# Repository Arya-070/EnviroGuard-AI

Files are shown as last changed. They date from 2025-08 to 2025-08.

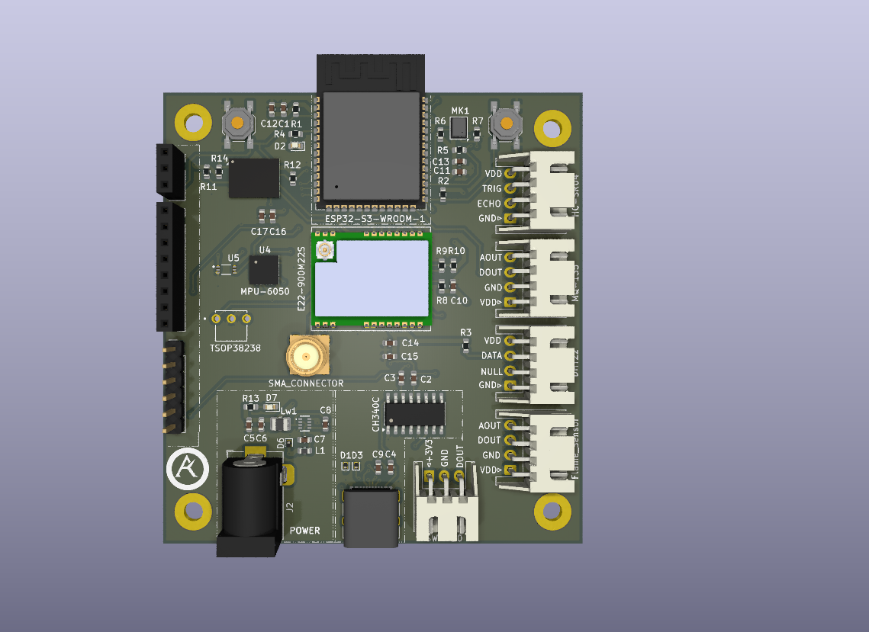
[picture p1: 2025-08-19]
IMAGES/3D_VIEW1.png

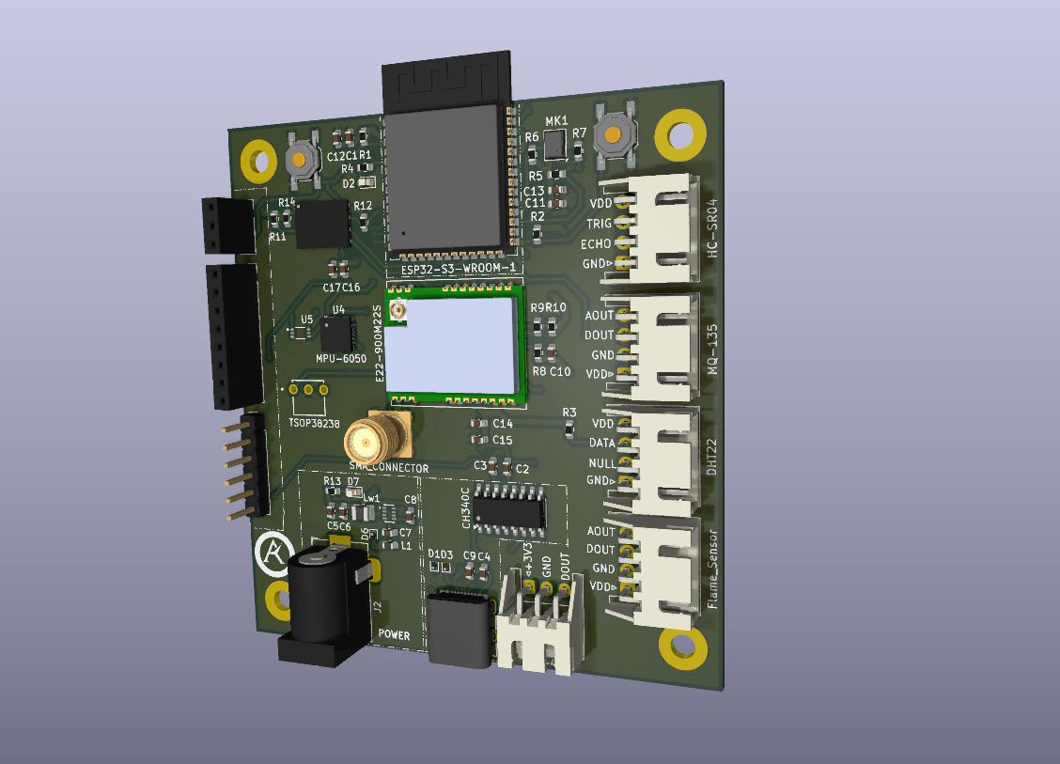
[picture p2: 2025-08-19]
IMAGES/3D_VIEW_2.png

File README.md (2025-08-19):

# 🚀 EnviroGuard-AI
### *A Smart, Modular Infrastructure Monitoring System Powered by Edge AI and ESP32-S3*

---

## 🌍 Overview
**EnviroGuard-AI** is a compact, modular, and powerful anomaly detection system built around the **ESP32-S3-WROOM-1** microcontroller. Designed specifically for smart infrastructure applications, this system brings together multiple environmental sensors, long-range wireless communication, and Edge AI capabilities.

With its **professionally designed 4-layer PCB**, onboard **LoRa (SX1262)**, **QSPI Flash** for TinyML models, and **I2S audio input**, it's ideal for detecting gas leaks, vibrations, fire hazards, and abnormal sounds in real-time. Its modular design makes it perfect for quick prototyping or field deployment.

---

## 🌟 Project Highlights
- 🛠️ Fully custom 4-layer **PCB designed in KiCad 7.0**
- 🔌 Powered via **USB-C** with onboard **CH340C USB-to-Serial** interface
- 💾 Includes **QSPI Flash** for storing Edge AI/TinyML models
- 🎤 Audio anomaly detection via **I2S MEMS microphone**
- 🌫️ Onboard sensors for gas, temperature, humidity, vibration, flame, and light
- 📡 Long-range communication using **SX1262 LoRa module**
- 🔋 Designed for **low-power, high-reliability** use cases
- 🧩 Modular expansion header for future hardware integrations

---

## 📌 GPIO Pinout & Connections

| GPIO Pin | Connected To | Function / Role |
|---|---|---|
| GPIO0 | SW_BOOT | Boot mode selection |
| GPIO1 | CH340C RXD | UART TX |
| GPIO3 | CH340C TXD | UART RX |
| GPIO10 | LED_STATUS | Status LED |
| GPIO4 | MQ135_DATA | Gas Sensor |
| GPIO5 | BH1750_SCL | Light Sensor (I2C) Clock |
| GPIO6 | EXP_IO1 | Expansion GPIO |
| GPIO12 | MPU6050_SDA | I2C Data (Accelerometer) |
| GPIO17 | MPU6050_SCL | I2C Clock (Accelerometer) |
| GPIO18 | FLAME_DO | Flame Sensor Digital Out |
| GPIO19 | MIC_CLK | I2S Clock |
| GPIO20 | MIC_DATA | I2S Data |
| GPIO21 | DHT22_DATA | Temp & Humidity Sensor |
| GPIO24 | LORA_BUSY | LoRa Busy Pin |
| GPIO25 | LORA_MOSI | SPI MOSI |
| GPIO26 | LORA_MISO | SPI MISO |
| GPIO31 | LORA_NSS | LoRa CS |
| GPIO32 | LORA_SCK | SPI Clock |
| GPIO34 | LORA_IRQ0 | LoRa Interrupt |
| GPIO36 | LORA_RST | LoRa Reset |
| GPIO35 | EXP_IO5 | Expansion GPIO |
| EN | EN Switch | Reset Circuit |

---

## 🧠 System Architecture

```mermaid
flowchart TD

    %% === Style Definitions ===
    classDef core fill:#ffe0f0,stroke:#d63384,stroke-width:1px,color:#000;
    classDef comm fill:#fff3cd,stroke:#ffc107,stroke-width:1px,color:#000;
    classDef sensor fill:#d1e7dd,stroke:#0f5132,stroke-width:1px,color:#000;
    classDef audio fill:#dbe4ff,stroke:#4c6ef5,stroke-width:1px,color:#000;
    classDef memory fill:#f8d7da,stroke:#842029,stroke-width:1px,color:#000;
    classDef power fill:#e2e3e5,stroke:#6c757d,stroke-width:1px,color:#000;
    classDef expansion fill:#e7f5ff,stroke:#228be6,stroke-width:1px,color:#000;

    %% === Main Power and MCU ===
    USB_C[USB-C Port]:::power --> Regulator[MP2333 Regulator]:::power
    Regulator --> ESP32S3[ESP32-S3 WROOM-1]:::core

    %% === Interfaces ===
    CH340C[CH340C USB-UART]:::comm --> ESP32S3

    %% === Peripherals ===
    ESP32S3 --> Flash[QSPI Flash Memory]:::memory
    ESP32S3 --> LoRa[SX1262 LoRa Module]:::comm
    ESP32S3 --> Audio[MEMS I2S Microphone]:::audio
    ESP32S3 --> Sensors[Sensor Hub]:::sensor
    ESP32S3 --> Expansion[Expansion IO Header]:::expansion

    %% === Sensors ===
    Sensors --> MQ135[MQ135 Gas Sensor]:::sensor
    Sensors --> MPU6050[MPU6050 Accelerometer]:::sensor
    Sensors --> Flame[Flame Sensor]:::sensor
    Sensors --> DHT22[DHT22 Temp & Humidity Sensor]:::sensor
    Sensors --> BH1750[BH1750 Light Sensor]:::sensor
```

---

## 🧩 Component Summary

| No. | Component | Interface | Description |
|-----|---|---|---|
| 1 | ESP32-S3-WROOM-1 | - | Main MCU with AI, BLE, WiFi |
| 2 | SX1262 LoRa Module | SPI | Long-range wireless communication |
| 3 | MEMS I2S Microphone | I2S | Captures audio for analysis |
| 4 | MQ135 | Analog | Gas and air quality sensing |
| 5 | MPU6050 | I2C | Vibration/motion detection |
| 6 | DHT22 | Digital | Temperature & Humidity |
| 7 | BH1750 | I2C | Ambient light measurement |
| 8 | Flame Sensor (4-pin) | Digital | Detects flame or fire presence |
| 9 | CH340C | UART | USB-to-Serial for flashing and debug |
| 10  | QSPI Flash (W25Q32JV)  | QSPI | Stores ML models for inference |
| 11  | USB-C Port | Power | Power and programming port |
| 12  | MP2333 Regulator | Power | Converts 5V to 3.3V efficiently |
| 13  | Expansion Header | GPIO | Breakout pins for add-ons and testing |

---

## 📁 Folder Structure
```bash
EnviroGuard-AI/
│
├── README.md               
├── LICENSE                  
├── .gitignore               
│
├── EnviroGuard-AI_KiCAD_File/      
│   ├── EnviroGuard-AI.kicad_sch    
│   ├── EnviroGuard-AI.kicad_pcb    
│   ├── EnviroGuard-AI.pro          
│   ├── SCH_AUDIO_INPUT.kicad_sch    
│   ├── SCH_COMMUNICATION.kicad_sch  
│   ├── SCH_ENV_SENSORS.kicad_sch   
│   ├── SCH_EXPANSION.kicad_sch    
│   ├── SCH_MCU_CORE.kicad_sch      
│   ├── SCH_POWER_MANAGEMENT.kicad_sch 
│   ├── SCH_QSPI_STORAGE.kicad_sch   
│             
│
├── GERBER/                  
│   └── EnviroGuard-AI-Gerber.zip
│
IMAGES/    
│     ├── 3D_VIEW_1.png
│     ├── 3D_VIEW_2.png
│     ├── B.CU.png
│     ├── F.CU.png
│     ├── In1.CU.png
│     ├── In2.CU.png
│     ├── EDITOR_VIEW.png
│     ├── SCH_AUDIO_INPUT.png
│     ├── SCH_COMMUNICATION.png
│     ├── SCH_ENV_SENSORS.png
│     ├── SCH_EXPANSION.png
│     ├── SCH_MCU_CORE.png
│     ├── SCH_POWER_MANAGEMENT.png
│     ├── SCH_QSPI_STORAGE.png
│     ├── SCHEMATIC_ROOT.png
│     ├── SYSTEM_ARCHITECTURE.png
│     └── COMPONENTS_DOWNLOADED              
└── Backup_ZIP/             
    └── EnviroGuard-AI-backups/

```

---

## 🌱 Future Improvements
- Add a buzzer or RGB LED for better visual/audio alerts
- Enable deep sleep mode to save power during idle states
- Integrate a solar charging module (e.g., TP4056 or BQ24210)
- LoRaWAN gateway integration with cloud sync
- Run a trained ML model for local anomaly classification
- Add a companion web dashboard or mobile app

---

## 🌐 License
This project is released under the **MIT License**. You’re free to use, modify, and share it as you like.

---

## 🤝 Contributions & Feedback
- Found an issue? Open a GitHub issue.
- Have ideas or want to contribute? Pull requests are welcome.
- Collaborators in AI, IoT, or hardware design — feel free to connect!

---

**Let’s build a smarter, safer world with modular edge intelligence — one node at a time. ✨**

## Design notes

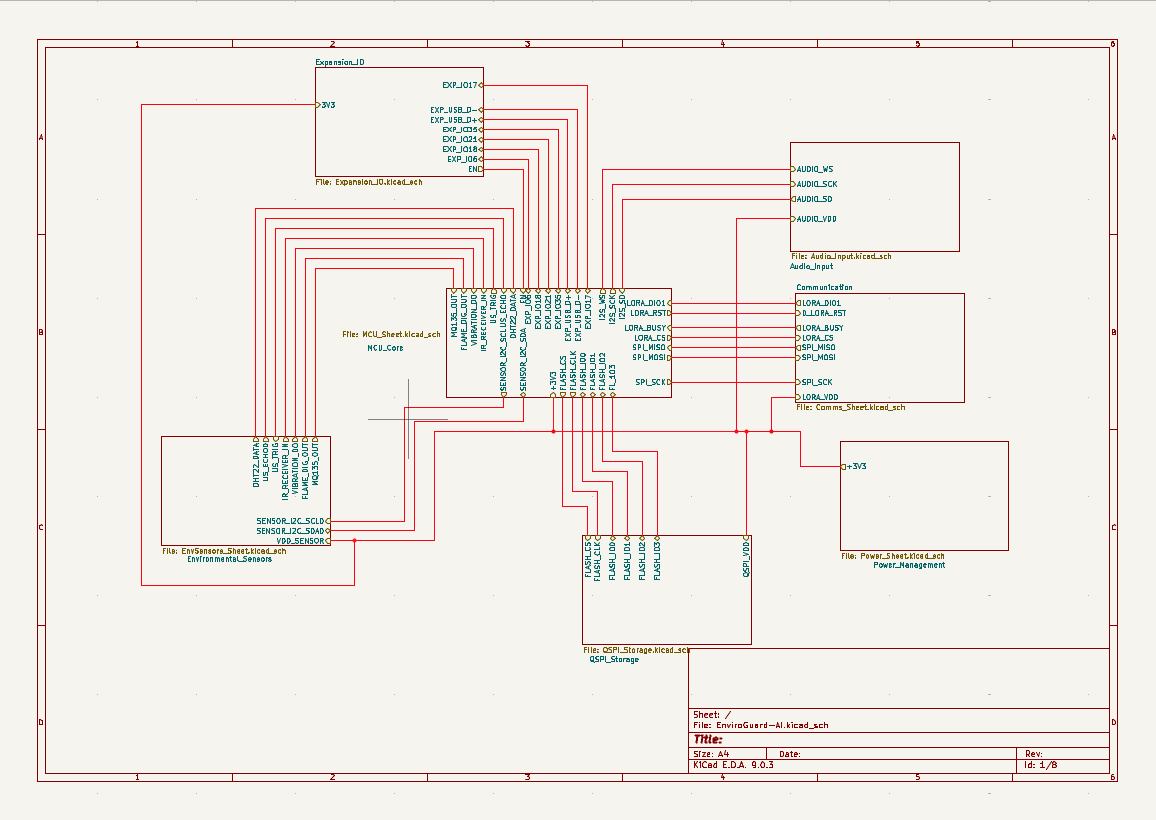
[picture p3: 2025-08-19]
IMAGES/SCHEMATIC_ROOT.png

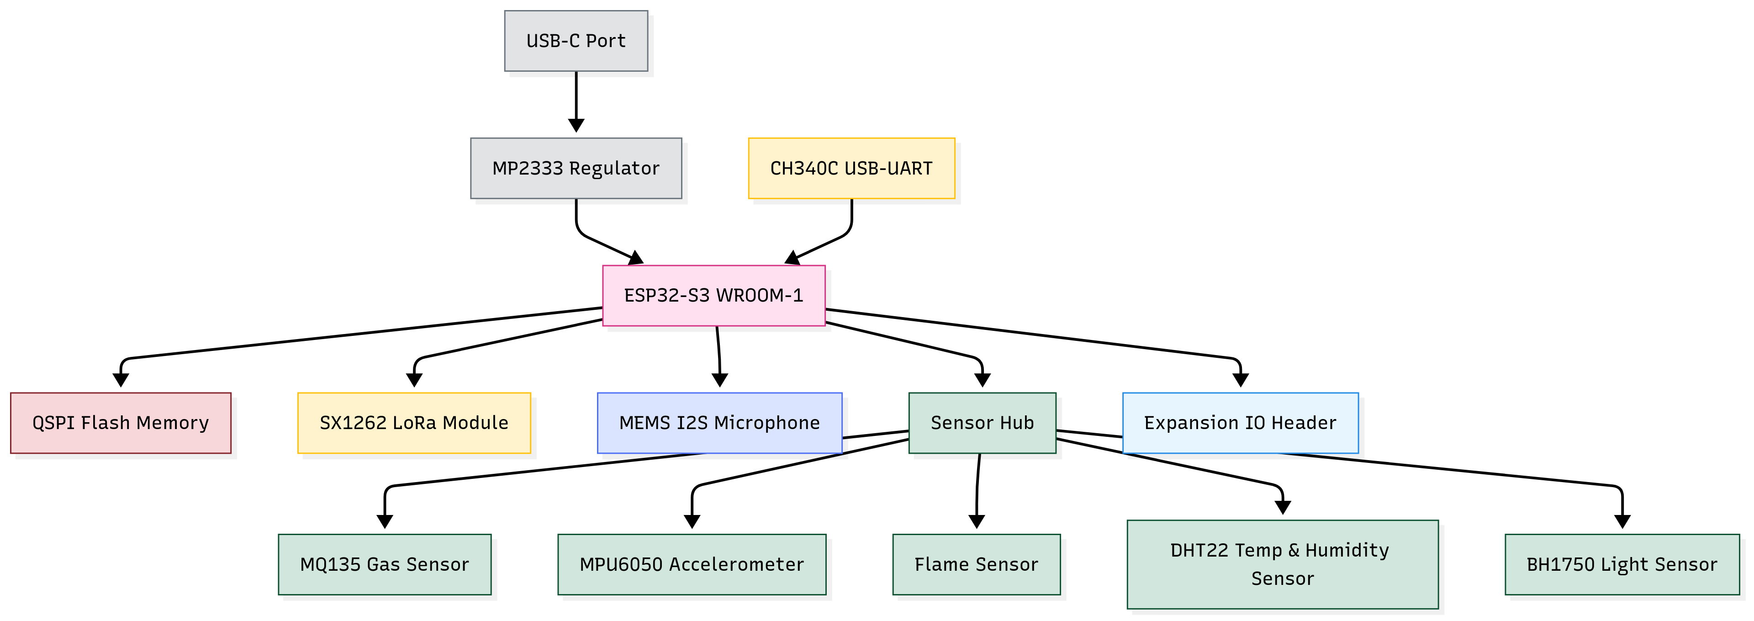
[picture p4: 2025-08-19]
IMAGES/SYSTEM_ARCHITECTURE.png

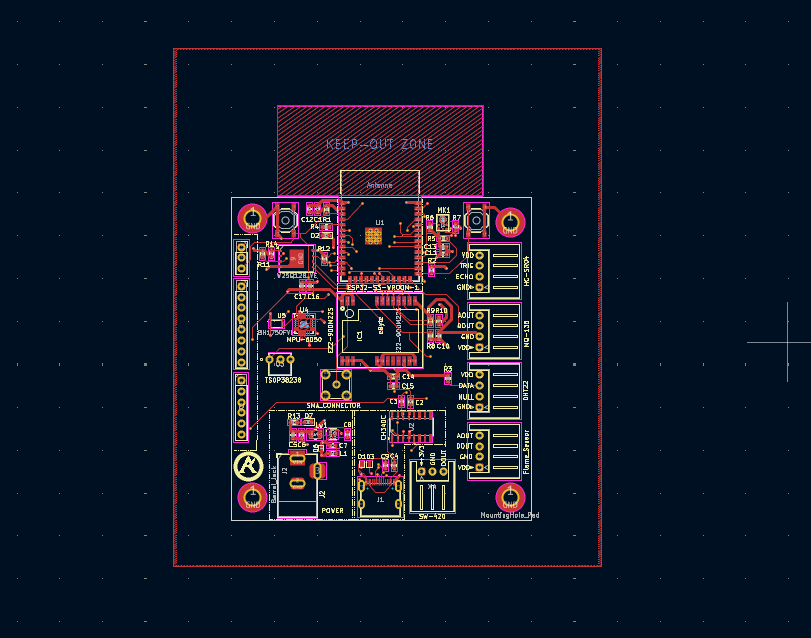
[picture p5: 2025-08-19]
IMAGES/F.CU.png

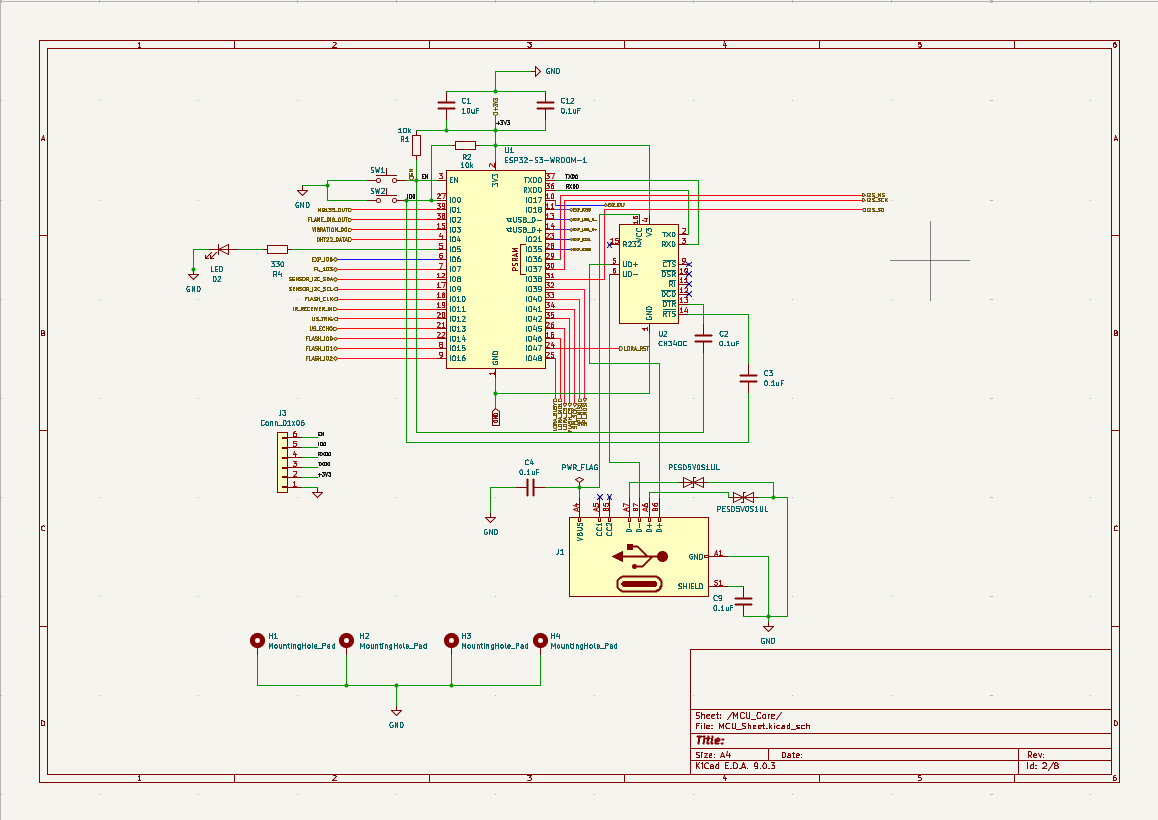
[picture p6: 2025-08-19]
IMAGES/SCH_MCU_CORE.png

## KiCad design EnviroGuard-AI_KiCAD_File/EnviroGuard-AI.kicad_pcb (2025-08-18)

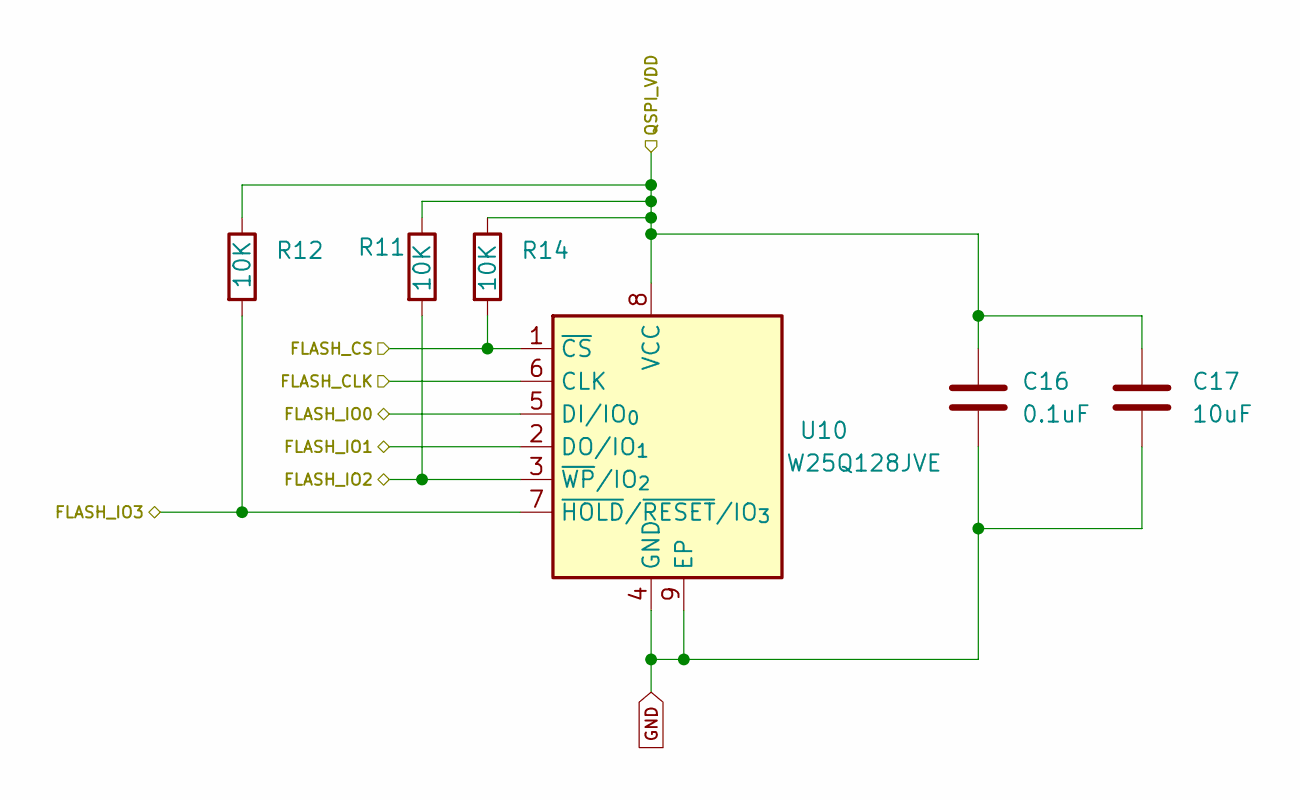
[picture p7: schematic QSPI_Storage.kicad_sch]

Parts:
C16: 0.1uF; C_0603_1608Metric
C17: 10uF; C_0603_1608Metric
R11, R12, R14: 10K; R_0603_1608Metric
U10: W25Q128JVE; WSON-8-1EP_8x6mm_P1.27mm_EP3.4x4.3mm

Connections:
/MCU_Core/+3V3: C16.1, C17.1, R11.1, R12.1, R14.1, U10.8 (VCC); also elsewhere on the board
/MCU_Core/FLASH_CLK: U10.6 (CLK); also elsewhere on the board
/MCU_Core/FLASH_CS: R14.2, U10.1 (~CS); also elsewhere on the board
/MCU_Core/FLASH_IO0: U10.5 (DI/IO_{0}); also elsewhere on the board
/MCU_Core/FLASH_IO1: U10.2 (DO/IO_{1}); also elsewhere on the board
/MCU_Core/FLASH_IO2: R11.2, U10.3 (~WP/IO_{2}); also elsewhere on the board
/MCU_Core/FL_1O3: R12.2, U10.7 (~HOLD/~RESET/IO_{3}); also elsewhere on the board
GND: C16.2, C17.2, U10.4 (GND), U10.9 (EP); also elsewhere on the board

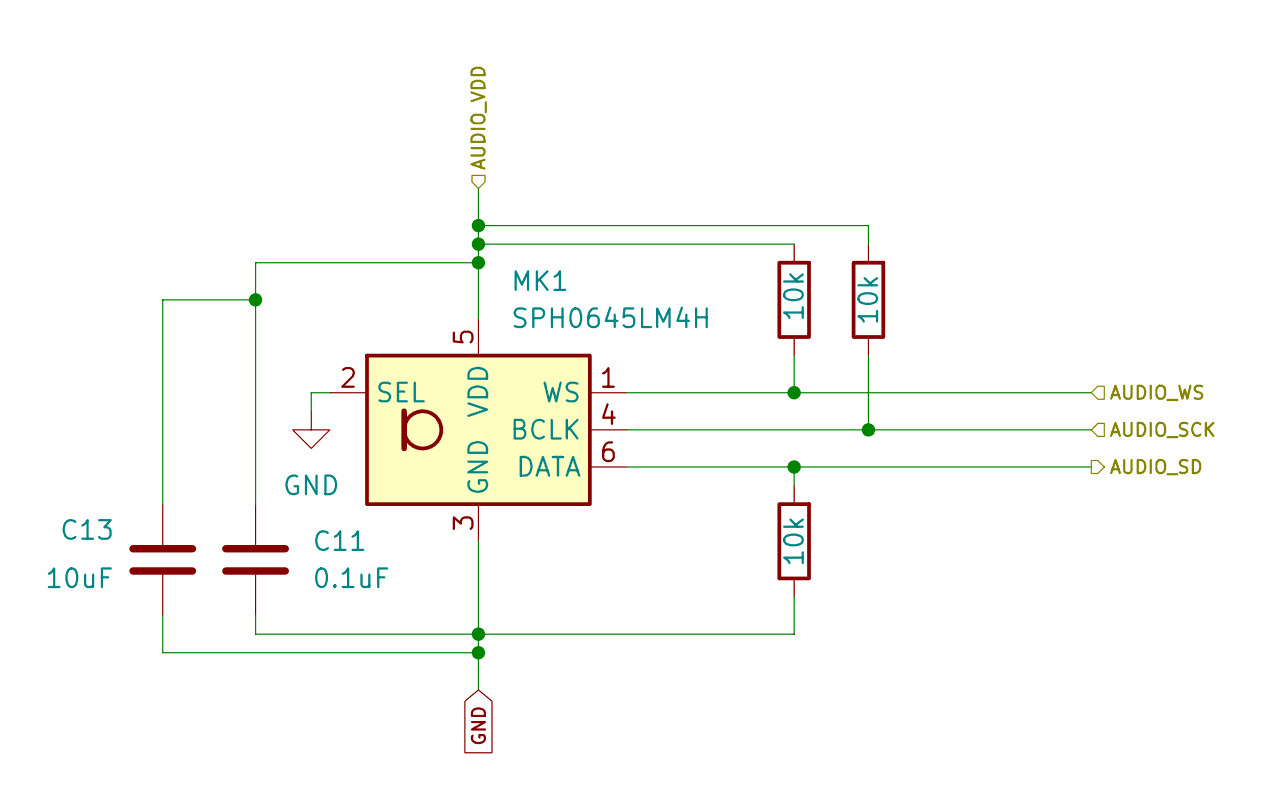
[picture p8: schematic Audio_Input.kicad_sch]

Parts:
C11: 0.1uF; C_0603_1608Metric
C13: 10uF; C_0603_1608Metric
MK1: SPH0645LM4H; Knowles_SPH0645LM4H-6_3.5x2.65mm
R5, R6, R7: 10k; R_0603_1608Metric

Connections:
/Audio_Input/AUDIO_SCK: MK1.4 (BCLK), R6.1; also elsewhere on the board
/Audio_Input/AUDIO_SD: MK1.6 (DATA), R7.2; also elsewhere on the board
/Audio_Input/AUDIO_WS: MK1.1 (WS), R5.1; also elsewhere on the board
/MCU_Core/+3V3: C11.1, C13.1, MK1.5 (VDD), R5.2, R6.2; also elsewhere on the board
GND: C11.2, C13.2, MK1.2 (SEL), MK1.3 (GND), R7.1; also elsewhere on the board

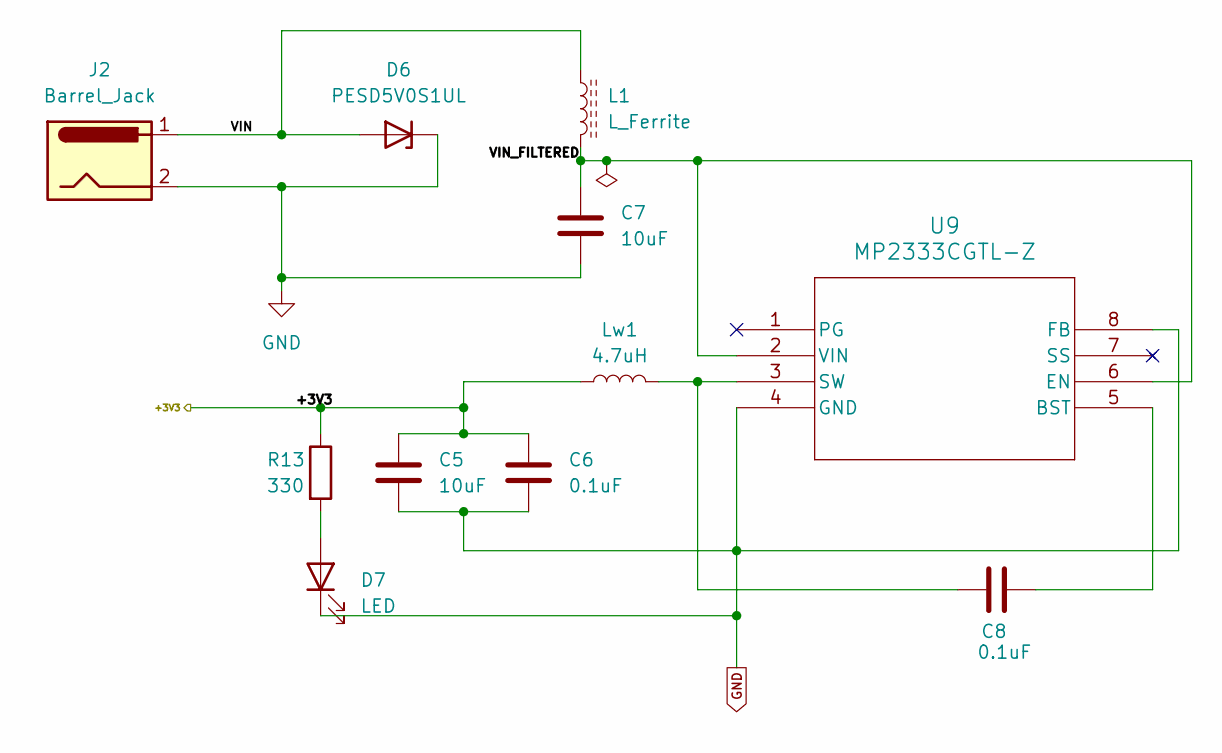
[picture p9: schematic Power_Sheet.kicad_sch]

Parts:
C5, C7: 10uF; C_0603_1608Metric
C6, C8: 0.1uF; C_0603_1608Metric
D6: PESD5V0S1UL; D_SOD-882
D7: LED; LED_0603_1608Metric
J2: Barrel_Jack; BarrelJack_Horizontal
L1: L_Ferrite; L_0603_1608Metric
Lw1: 4.7uH; L_1008_2520Metric
R13: 330; R_0603_1608Metric
U9: MP2333CGTL-Z; SOT583_MP2333C_MNP

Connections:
/MCU_Core/+3V3: C5.1, C6.1, Lw1.1, R13.1; also elsewhere on the board
/Power_Management/VIN: D6.2 (A), J2.1, L1.1
/Power_Management/VIN_FILTERED: C7.1, L1.2, U9.2 (VIN), U9.6 (EN)
GND: C5.2, C6.2, C7.2, D6.1 (K), D7.1 (K), J2.2, U9.4 (GND), U9.8 (FB); also elsewhere on the board
unnamed: D7.2 (A), R13.2
unnamed: C8.1, U9.5 (BST)
unnamed: C8.2, Lw1.2, U9.3 (SW)

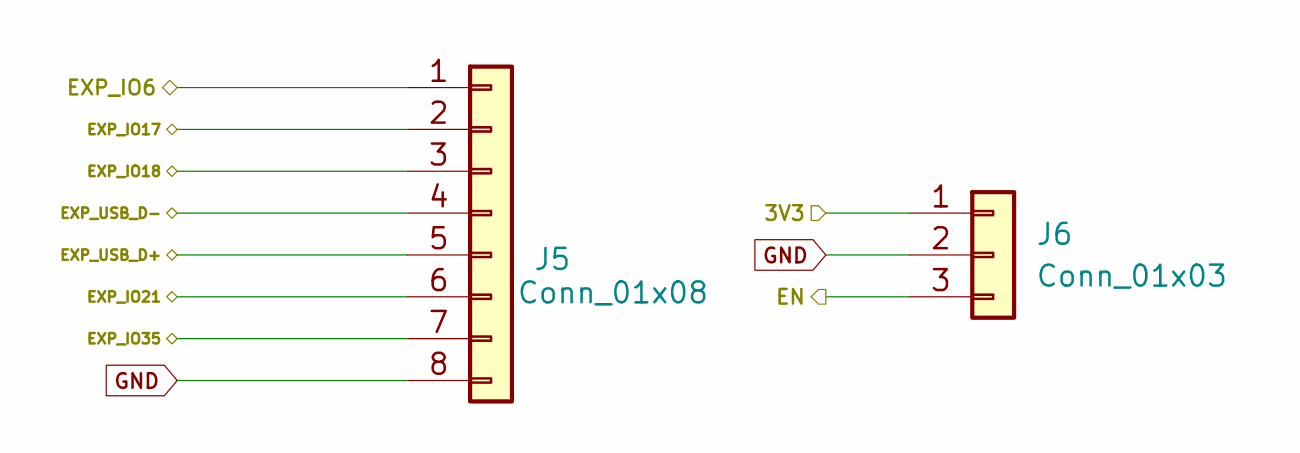
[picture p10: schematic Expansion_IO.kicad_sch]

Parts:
J5: Conn_01x08; PinSocket_1x08_P2.54mm_Vertical
J6: Conn_01x03; PinSocket_1x03_P2.54mm_Vertical

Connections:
/Expansion_IO/EXP_IO6: J5.1; also elsewhere on the board
/Expansion_IO/EXP_IO17: J5.2; also elsewhere on the board
/Expansion_IO/EXP_IO18: J5.3; also elsewhere on the board
/Expansion_IO/EXP_IO21: J5.6; also elsewhere on the board
/Expansion_IO/EXP_IO35: J5.7; also elsewhere on the board
/Expansion_IO/EXP_USB_D+: J5.5; also elsewhere on the board
/Expansion_IO/EXP_USB_D-: J5.4; also elsewhere on the board
/MCU_Core/+3V3: J6.1; also elsewhere on the board
/MCU_Core/EN: J6.3; also elsewhere on the board
GND: J5.8, J6.2; also elsewhere on the board

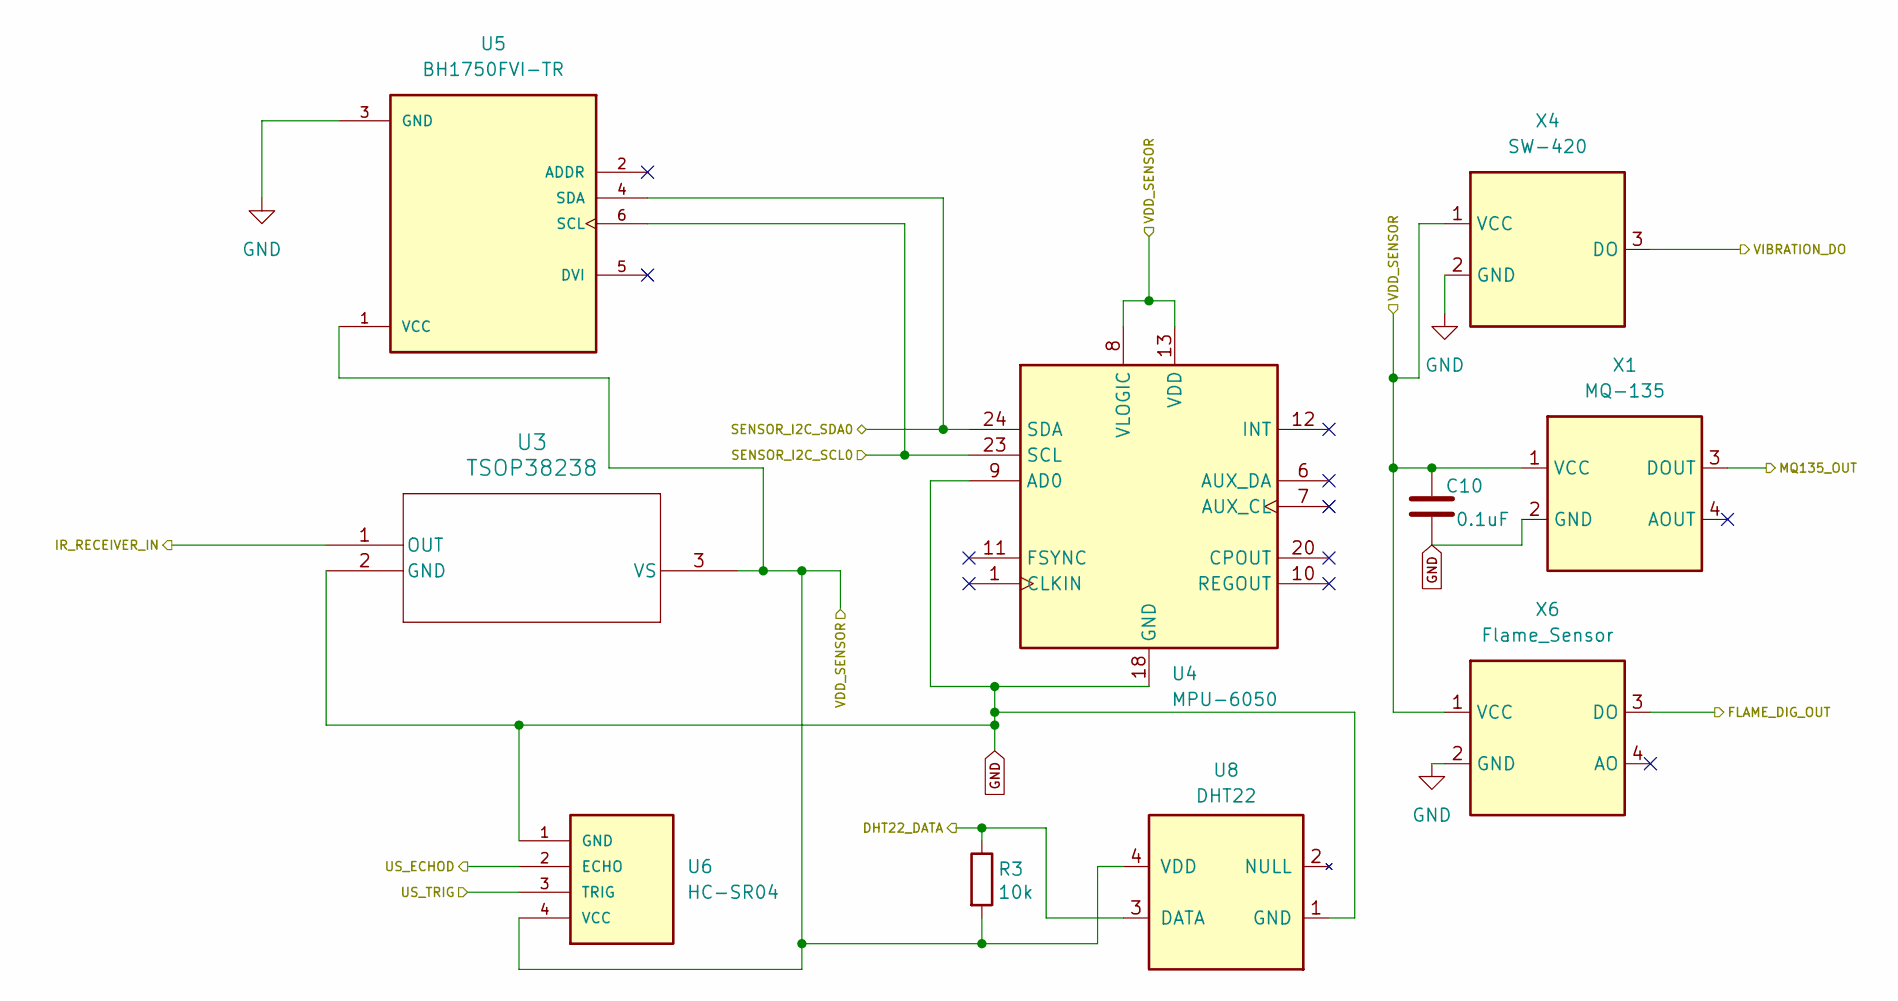
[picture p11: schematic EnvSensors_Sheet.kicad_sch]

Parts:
C10: 0.1uF; C_0603_1608Metric
R3: 10k; R_0603_1608Metric
U3: TSOP38238; TSOP382
U4: MPU-6050; InvenSense_QFN-24_4x4mm_P0.5mm
U5: BH1750FVI-TR; XDCR_BH1750FVI-TR; PARTREV D
U6: HC-SR04; JST_XH_S4B-XH-A_1x04_P2.50mm_Horizontal
U8: DHT22; JST_XH_S4B-XH-A_1x04_P2.50mm_Horizontal
X1: MQ-135; JST_XH_S4B-XH-A_1x04_P2.50mm_Horizontal
X4: SW-420; JST_XH_S3B-XH-A_1x03_P2.50mm_Horizontal
X6: Flame_Sensor; JST_XH_S4B-XH-A_1x04_P2.50mm_Horizontal

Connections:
/Environmental_Sensors/DHT22_DATA: R3.1, U8.3 (DATA); also elsewhere on the board
/Environmental_Sensors/FLAME_DIG_OUT: X6.3 (DO); also elsewhere on the board
/Environmental_Sensors/IR_RECEIVER_IN: U3.1 (OUT); also elsewhere on the board
/Environmental_Sensors/MQ135_OUT: X1.3 (DOUT); also elsewhere on the board
/Environmental_Sensors/SENSOR_I2C_SCL0: U4.23 (SCL), U5.6 (SCL); also elsewhere on the board
/Environmental_Sensors/SENSOR_I2C_SDA0: U4.24 (SDA), U5.4 (SDA); also elsewhere on the board
/Environmental_Sensors/US_ECHOD: U6.2 (ECHO); also elsewhere on the board
/Environmental_Sensors/US_TRIG: U6.3 (TRIG); also elsewhere on the board
/Environmental_Sensors/VIBRATION_DO: X4.3 (DO); also elsewhere on the board
/MCU_Core/+3V3: C10.1, R3.2, U3.3 (VS), U4.8 (VLOGIC), U4.13 (VDD), U5.1 (VCC), U6.4 (VCC), U8.4 (VDD), X1.1 (VCC), X4.1 (VCC), X6.1 (VCC); also elsewhere on the board
GND: C10.2, U3.2 (GND), U4.9 (AD0), U4.18 (GND), U5.3 (GND), U6.1 (GND), U8.1 (GND), X1.2 (GND), X4.2 (GND), X6.2 (GND); also elsewhere on the board

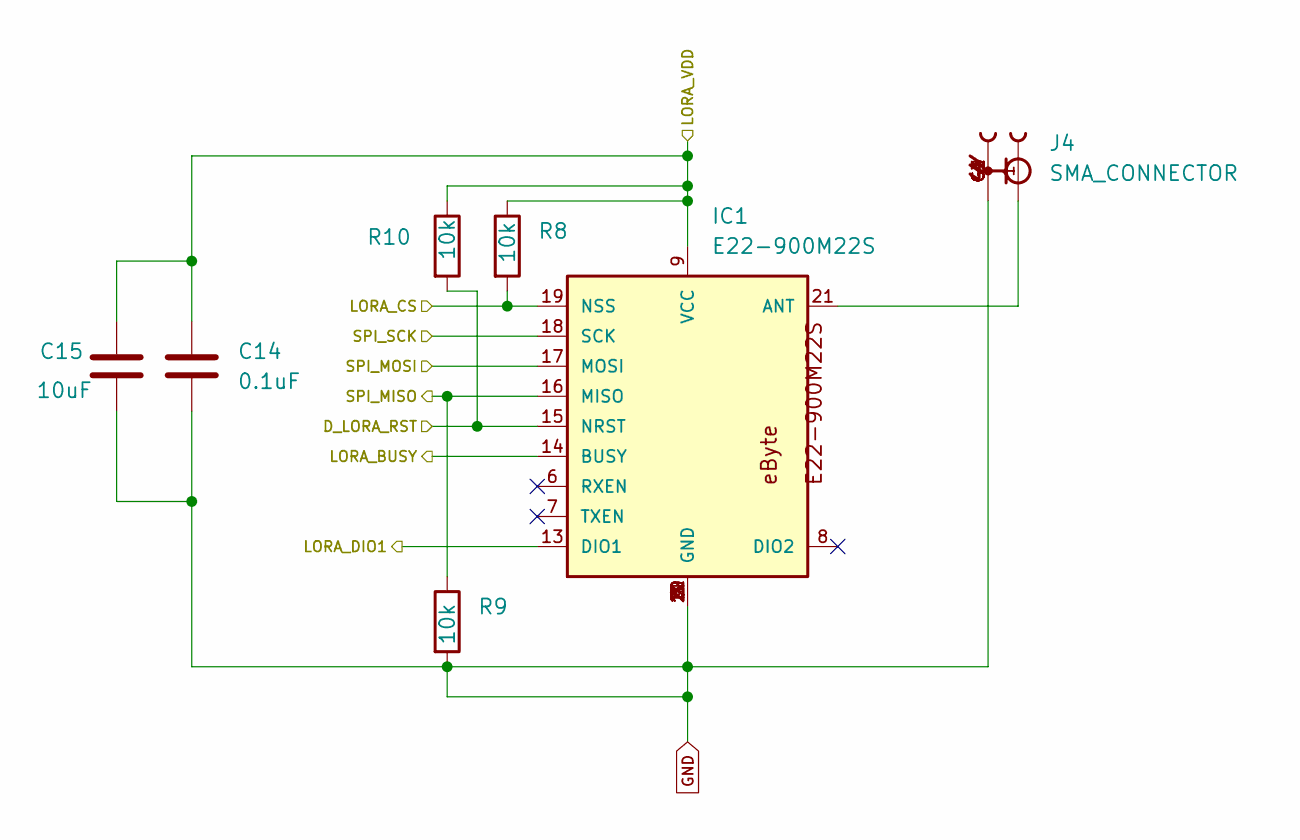
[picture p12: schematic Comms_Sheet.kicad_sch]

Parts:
C14: 0.1uF; C_0603_1608Metric
C15: 10uF; C_0603_1608Metric
IC1: E22-900M22S
J4: SMA_CONNECTOR; LPRS_SMA_CONNECTOR; PARTREV 1.3
R8, R9, R10: 10k; R_0603_1608Metric

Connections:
/Communication/D_LORA_RST: IC1.15 (NRST), R10.2; also elsewhere on the board
/Communication/LORA_BUSY: IC1.14 (BUSY); also elsewhere on the board
/Communication/LORA_CS: IC1.19 (NSS), R8.2; also elsewhere on the board
/Communication/LORA_DIO1: IC1.13 (DIO1); also elsewhere on the board
/Communication/SPI_MISO: IC1.16 (MISO), R9.1; also elsewhere on the board
/Communication/SPI_MOSI: IC1.17 (MOSI); also elsewhere on the board
/Communication/SPI_SCK: IC1.18 (SCK); also elsewhere on the board
/MCU_Core/+3V3: C14.1, C15.1, IC1.9 (VCC), R8.1, R10.1; also elsewhere on the board
GND: C14.2, C15.2, IC1.1 (GND), IC1.2 (GND), IC1.3 (GND), IC1.4 (GND), IC1.5 (GND), IC1.10 (GND), IC1.11 (GND), IC1.12 (GND), IC1.20 (GND), IC1.22 (GND), J4.G1, J4.G2, J4.G3, J4.G4, R9.2; also elsewhere on the board
unnamed: IC1.21 (ANT), J4.1

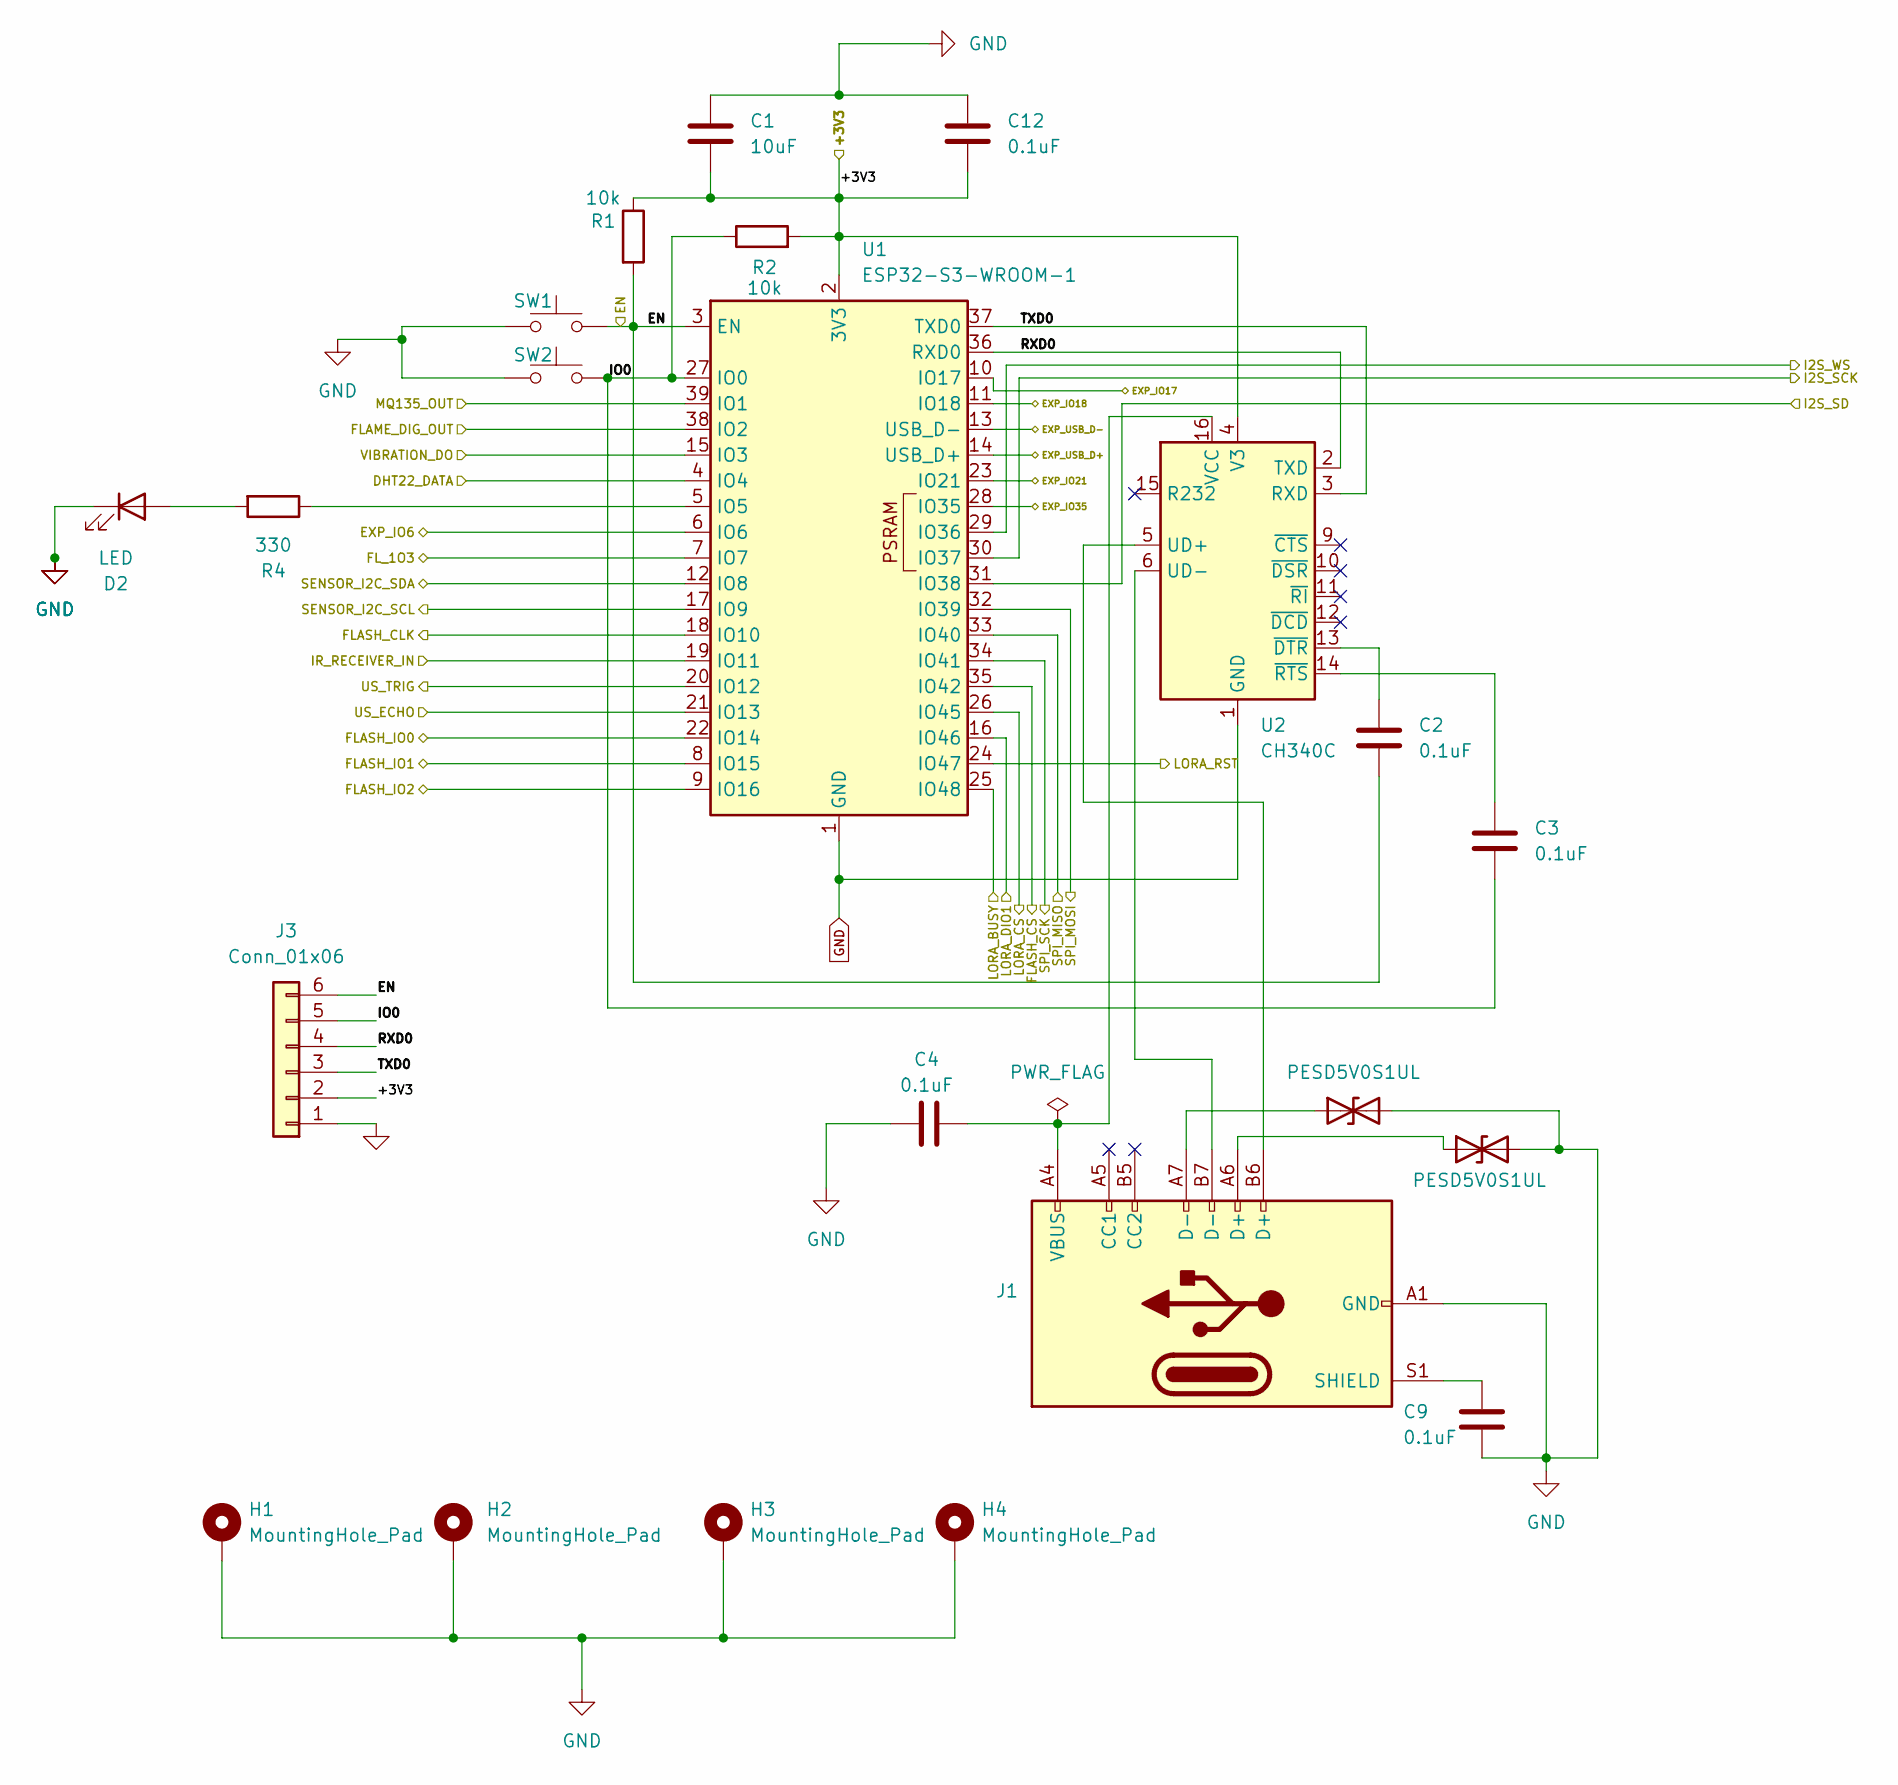
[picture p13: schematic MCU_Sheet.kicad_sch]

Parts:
C1: 10uF; C_0603_1608Metric
C2, C3, C4, C9, C12: 0.1uF; C_0603_1608Metric
D1, D3: PESD5V0S1UL; D_SOD-882
D2: LED; LED_0603_1608Metric
H1, H2, H3, H4: MountingHole_Pad; MountingHole_3.2mm_M3_Pad
J1: USB_C_Receptacle_USB2.0_14P; USB_C_Receptacle_HRO_TYPE-C-31-M-12
J3: Conn_01x06; PinHeader_1x06_P2.54mm_Vertical
R1, R2: 10k; R_0603_1608Metric
R4: 330; R_0603_1608Metric
SW1, SW2: SW_Push; SW_SPST_TL3342
U1: ESP32-S3-WROOM-1
U2: CH340C; SOIC-16_3.9x9.9mm_P1.27mm

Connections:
/Audio_Input/AUDIO_SCK: U1.30 (IO37); also elsewhere on the board
/Audio_Input/AUDIO_SD: U1.31 (IO38); also elsewhere on the board
/Audio_Input/AUDIO_WS: U1.29 (IO36); also elsewhere on the board
/Communication/D_LORA_RST: U1.24 (IO47); also elsewhere on the board
/Communication/LORA_BUSY: U1.25 (IO48); also elsewhere on the board
/Communication/LORA_CS: U1.26 (IO45); also elsewhere on the board
/Communication/LORA_DIO1: U1.16 (IO46); also elsewhere on the board
/Communication/SPI_MISO: U1.33 (IO40); also elsewhere on the board
/Communication/SPI_MOSI: U1.32 (IO39); also elsewhere on the board
/Communication/SPI_SCK: U1.34 (IO41); also elsewhere on the board
/Environmental_Sensors/DHT22_DATA: U1.4 (IO4); also elsewhere on the board
/Environmental_Sensors/FLAME_DIG_OUT: U1.38 (IO2); also elsewhere on the board
/Environmental_Sensors/IR_RECEIVER_IN: U1.19 (IO11); also elsewhere on the board
/Environmental_Sensors/MQ135_OUT: U1.39 (IO1); also elsewhere on the board
/Environmental_Sensors/SENSOR_I2C_SCL0: U1.17 (IO9); also elsewhere on the board
/Environmental_Sensors/SENSOR_I2C_SDA0: U1.12 (IO8); also elsewhere on the board
/Environmental_Sensors/US_ECHOD: U1.21 (IO13); also elsewhere on the board
/Environmental_Sensors/US_TRIG: U1.20 (IO12); also elsewhere on the board
/Environmental_Sensors/VIBRATION_DO: U1.15 (IO3); also elsewhere on the board
/Expansion_IO/EXP_IO6: U1.6 (IO6); also elsewhere on the board
/Expansion_IO/EXP_IO17: U1.10 (IO17); also elsewhere on the board
/Expansion_IO/EXP_IO18: U1.11 (IO18); also elsewhere on the board
/Expansion_IO/EXP_IO21: U1.23 (IO21); also elsewhere on the board
/Expansion_IO/EXP_IO35: U1.28 (IO35); also elsewhere on the board
/Expansion_IO/EXP_USB_D+: U1.14 (USB_D+); also elsewhere on the board
/Expansion_IO/EXP_USB_D-: U1.13 (USB_D-); also elsewhere on the board
/MCU_Core/+3V3: C1.2, C12.2, J3.2, R1.1, R2.2, U1.2 (3V3), U2.4 (V3); also elsewhere on the board
/MCU_Core/EN: C2.1, J3.6, R1.2, SW1.2, U1.3 (EN); also elsewhere on the board
/MCU_Core/FLASH_CLK: U1.18 (IO10); also elsewhere on the board
/MCU_Core/FLASH_CS: U1.35 (IO42); also elsewhere on the board
/MCU_Core/FLASH_IO0: U1.22 (IO14); also elsewhere on the board
/MCU_Core/FLASH_IO1: U1.8 (IO15); also elsewhere on the board
/MCU_Core/FLASH_IO2: U1.9 (IO16); also elsewhere on the board
/MCU_Core/FL_1O3: U1.7 (IO7); also elsewhere on the board
/MCU_Core/IO0: C3.1, J3.5, R2.1, SW2.2, U1.27 (IO0)
/MCU_Core/RXD0: J3.4, U1.36 (RXD0), U2.2 (TXD)
/MCU_Core/TXD0: J3.3, U1.37 (TXD0), U2.3 (RXD)
GND: C1.1, C4.1, C9.2, C12.1, D1.2 (A2), D2.1 (K), D3.2 (A2), H1.1, H2.1, H3.1, H4.1, J1.A1 (GND), J1.A12 (GND), J1.B1 (GND), J1.B12 (GND), J3.1, SW1.1, SW2.1, U1.1 (GND), U1.40 (GND), U1.41 (GND), U2.1 (GND); also elsewhere on the board
unnamed: D1.1 (A1), J1.A7 (D-)
unnamed: D2.2 (A), R4.2
unnamed: D3.1 (A1), J1.A6 (D+)
unnamed: C9.1, J1.S1 (SHIELD)
unnamed: R4.1, U1.5 (IO5)
unnamed: J1.B6 (D+), U2.5 (UD+)
unnamed: J1.B7 (D-), U2.6 (UD-)
unnamed: C4.2, J1.A4 (VBUS), J1.A9 (VBUS), J1.B4 (VBUS), J1.B9 (VBUS), U2.16 (VCC)
unnamed: C2.2, U2.13 (~DTR)
unnamed: C3.2, U2.14 (~RTS)

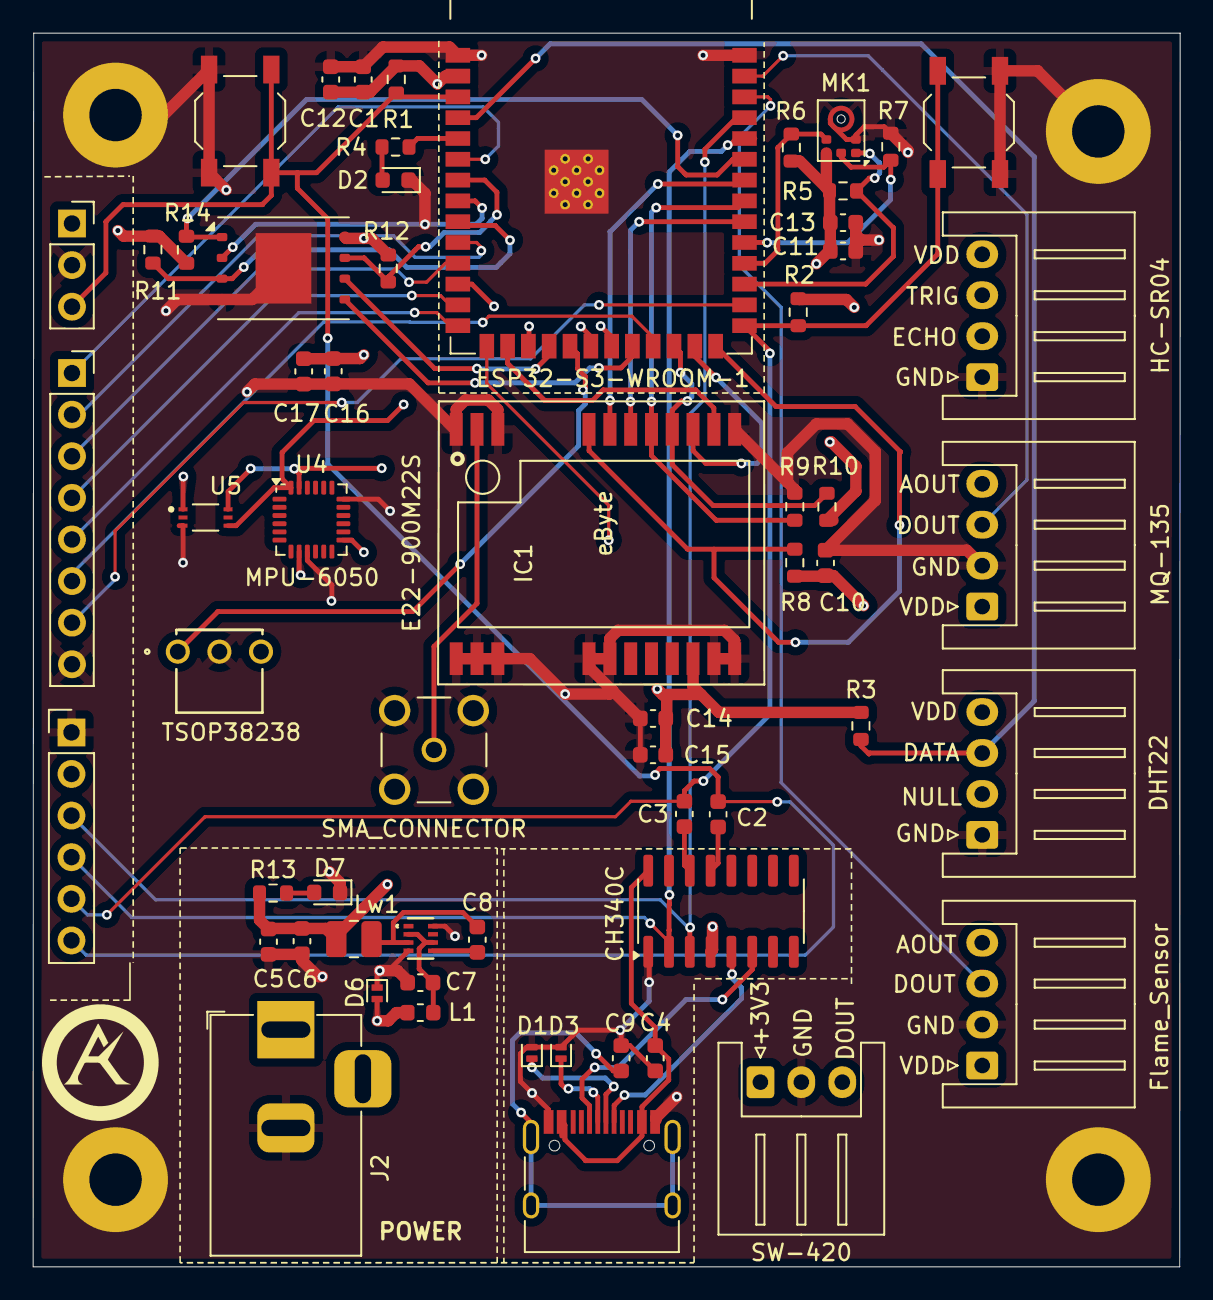
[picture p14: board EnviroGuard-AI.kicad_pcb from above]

Board: 4 copper layers, 70.0 x 75.3 mm, 64 parts (0 on the bottom side), 54 nets.
